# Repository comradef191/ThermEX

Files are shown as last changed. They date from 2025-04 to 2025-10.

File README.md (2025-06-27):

# ThermEX
A BlackPill powered expansion board for Klipper 3D printers, allowing the use of numerous additional Thermistors.

- Can be stacked ontop of or underneith Nyoomies using appropiate spacers
- OpenSource Hardware, licensed under the [OHLv2-S](https://opensource.org/license/cern-ohl-s)
- 10 thermistors wired directly to the STM32
- 16 additional thermistors wired up via 4 ADS1115 ICs
- Powered directly from the USB port
- Uses an ultra-low-noise [TPS7A2033](https://www.ti.com/product/TPS7A20/part-details/TPS7A2033PDBVR) 300mA 3.3v voltage regulator to power all expansion headers and the ADS1115s
- Features native support for the STM32F4x1 BlackPill, with the unused extra GPIO being broken out to a labelled expansion header alongside 3v3 & GND
- Breaks out the I2C2 & I2C3 busses to a pair of dedicated 4-pin JST-XH connectors
- Breaks out the SPI2 bus to a dedicated header, alongside PB12 to act as chip-select

# NOTICE
if you are ordering a batch of PCBs, please for the love of god please use the pre-made gerber files in the [Releases tab](https://github.com/comradef191/ThermEX/releases) instead of downloading the repo, ignoring KiCADs warning you haven't got [a font installed](https://github.com/ETBCOR/nasin-nanpa), and then exporting your own files which both have the I2C bus shorted out (rendering only 10 thermistor ports usable) due to the missing font breaking artwork on the copper layer plus has had markings crediting me destroyed.


## Vendors
UK / EU
- None... yet!

Contact me on Discord if you want to add yourself to this list!

## Bill of Materials
This BoM lists exclusively through-hole components, as SMD components will be assembled for you by JLCPCB
|  Component |QTY | Cost  |  Comment |  Sourcing URL |
|---|----|---|---|---|
|JST-XH 2-Pin | 26 | $0.39 | Thermistor Ports | https://www.lcsc.com/product-detail/Wire-To-Board-Connector_DEALON-XH-D-2A_C5160911.html |
|JST-XH 4-Pin | 2  | $0.52 | I2C Ports | https://www.lcsc.com/product-detail/Wire-To-Board-Connector_JST-B4B-XH-A-LF-SN_C144395.html |
|2.54 Socket, 1x20 | 2  | $0.81 | STM32 Socket | https://www.lcsc.com/product-detail/Female-Headers_Shenzhen-Kinghelm-Elec-KH-2-54FH-1X20P-H8-5_C2905423.html |
|2.54 Header, 2x5 | 3  | $0.40 | GPIO; Cut-Down for SPI | https://www.lcsc.com/product-detail/Pin-Headers_HanElectricity-2541WV-2x05P_C5383106.html |
|STM32F401 Blackpill | 1  | $3.25 | Main controller | https://www.aliexpress.com/item/1005006127461676.html |

# Gallery
*As of 09APR25 no ThermEX26 boards have been produced, thus only KiCad Renders are present currently* 



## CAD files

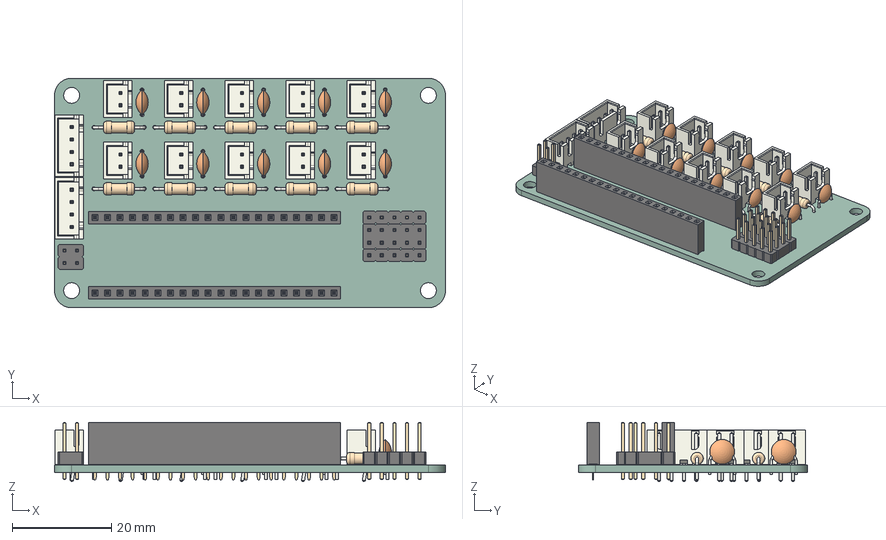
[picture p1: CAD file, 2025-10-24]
Resources/ThermEX10-Simple.step
78.8 x 46.3 x 11.9 mm
R_Axial_DIN0207_L6.3mm_D2.5mm_P10.16mm_Horizontal x 10
C_Disc_D5.0mm_W2.5mm_P5.00mm x 10
PinSocket_1x20_P2.54mm_Vertical x 2
JST_XH_B2B-XH-A_1x02_P2.50mm_Vertical x 10
PinHeader_1x05_P2.54mm_Vertical x 2
PinHeader_2x05_P2.54mm_Vertical
PinHeader_2x02_P2.54mm_Vertical
JST_XH_B4B-XH-A_1x04_P2.50mm_Vertical x 2
ThermEX-Simple_PCB

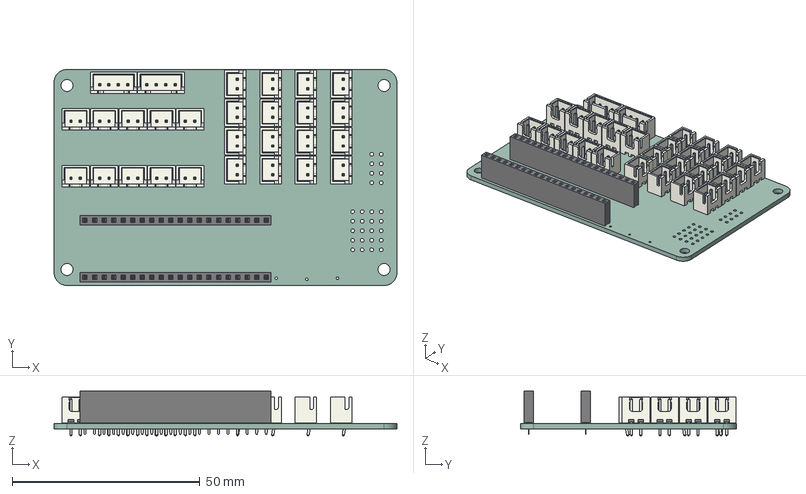
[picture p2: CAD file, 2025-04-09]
Resources/ThermEX26.step
91.3 x 57.5 x 11.9 mm
JST_XH_B2B-XH-A_1x02_P2.50mm_Vertical x 26
JST_XH_B4B-XH-A_1x04_P2.50mm_Vertical x 2
PinSocket_1x20_P2.54mm_Vertical x 2
ThermEX26_PCB

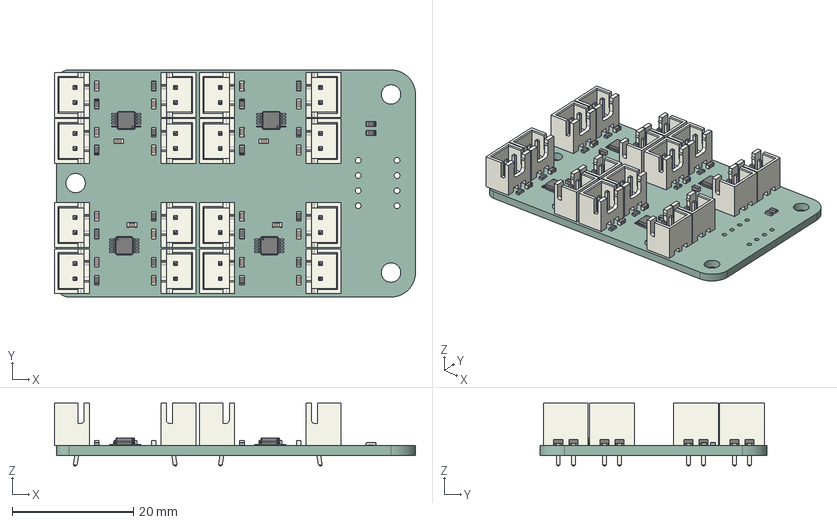
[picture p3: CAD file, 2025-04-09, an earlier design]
LegacyVersions/ThermEX16-V1/ThermEX16.step
59.6 x 37.5 x 10.4 mm
R_0603_1608Metric x 18
JST_B2B_XH_A x 16
C_0603_1608Metric x 20
VSSOP_10_3x3mm_P05mm x 4
ADCExpander_PCB

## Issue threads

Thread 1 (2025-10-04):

Eliminate I2C Bus components

Traveler61, 2025-10-04:
Can you please create a version with the I2C components. I realize it will mean less ports but 10 is enough. Having print failures during large prints, because Klipper can not handle bus fault, is not a good thing. Switching to Kalico is not an option for me.

comradef191, 2025-10-05:
already exists although hasn't been tested
https://github.com/comradef191/ThermEX/tree/main/LegacyVersions/ThermEX10

here's the exported files for that version:

[ThermEX10.zip](https://github.com/user-attachments/files/22705046/ThermEX10.zip)
[positions.csv](https://github.com/user-attachments/files/22705044/positions.csv)
[bom.csv](https://github.com/user-attachments/files/22705045/bom.csv)

Traveler61, 2025-10-06:
Thank you, I had not looked there.

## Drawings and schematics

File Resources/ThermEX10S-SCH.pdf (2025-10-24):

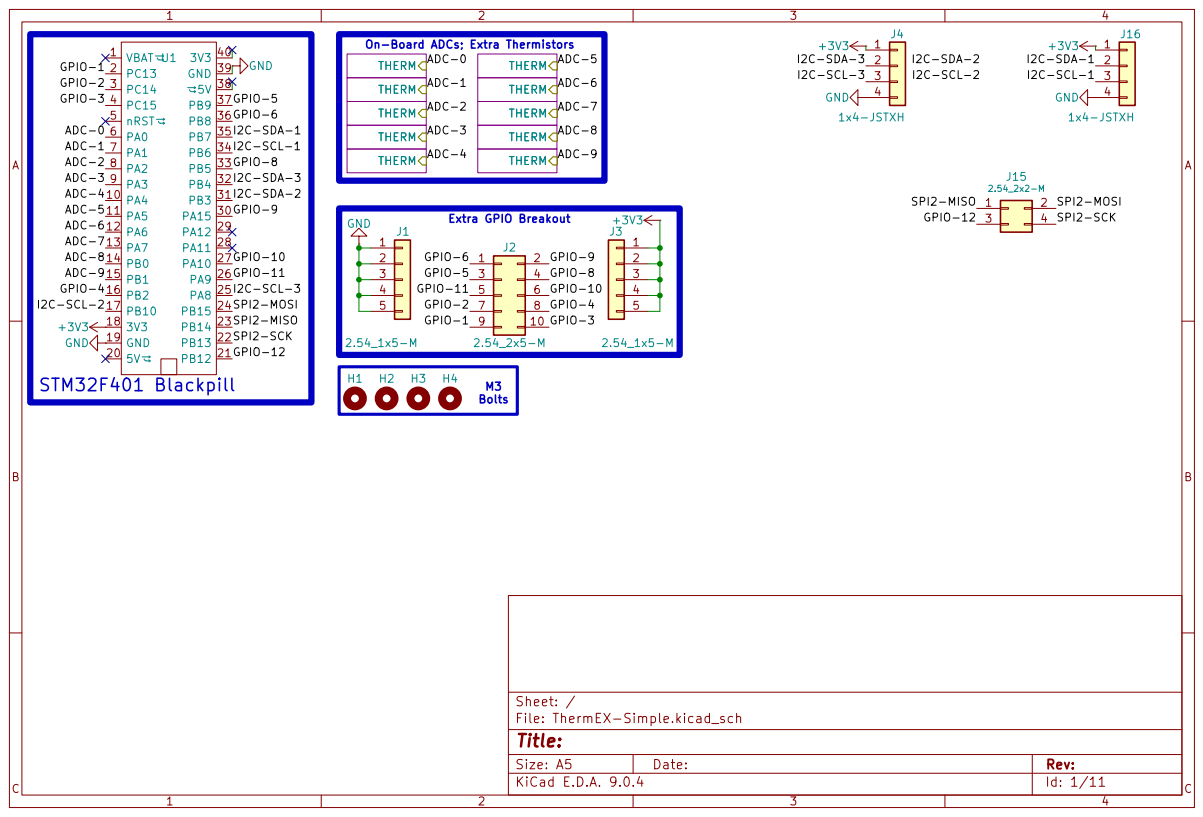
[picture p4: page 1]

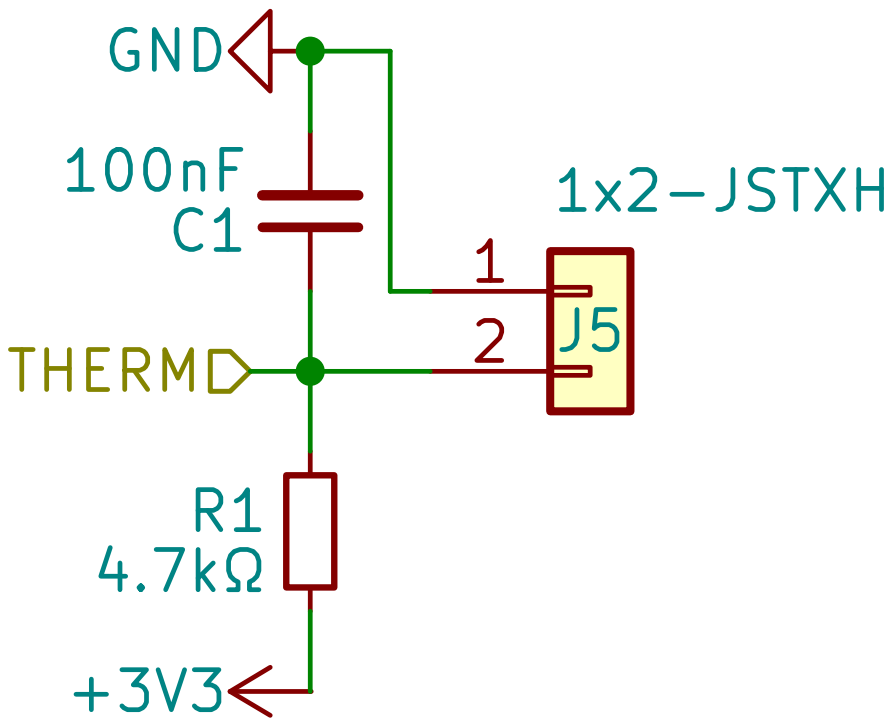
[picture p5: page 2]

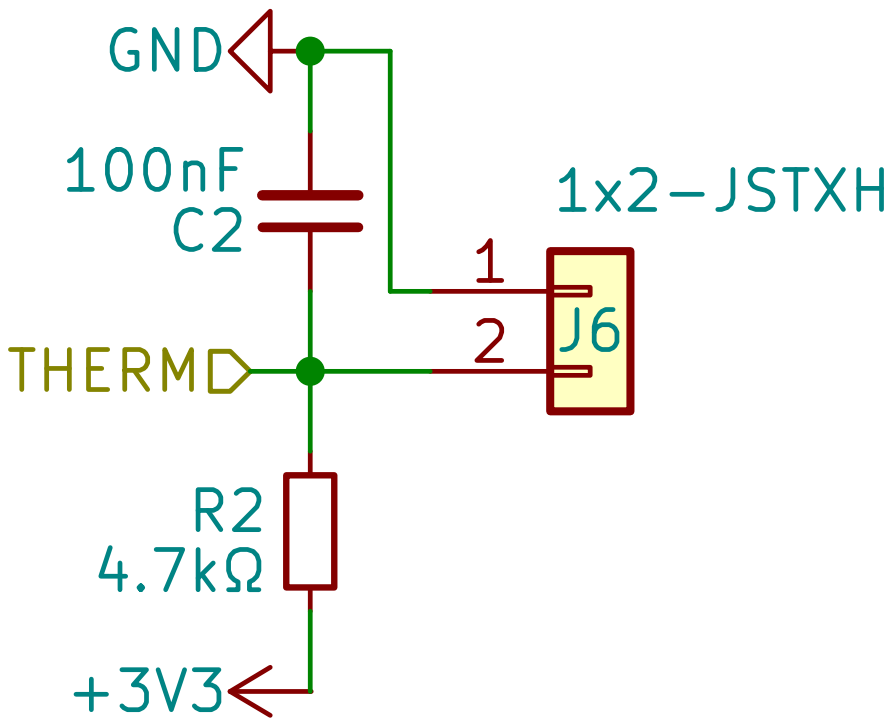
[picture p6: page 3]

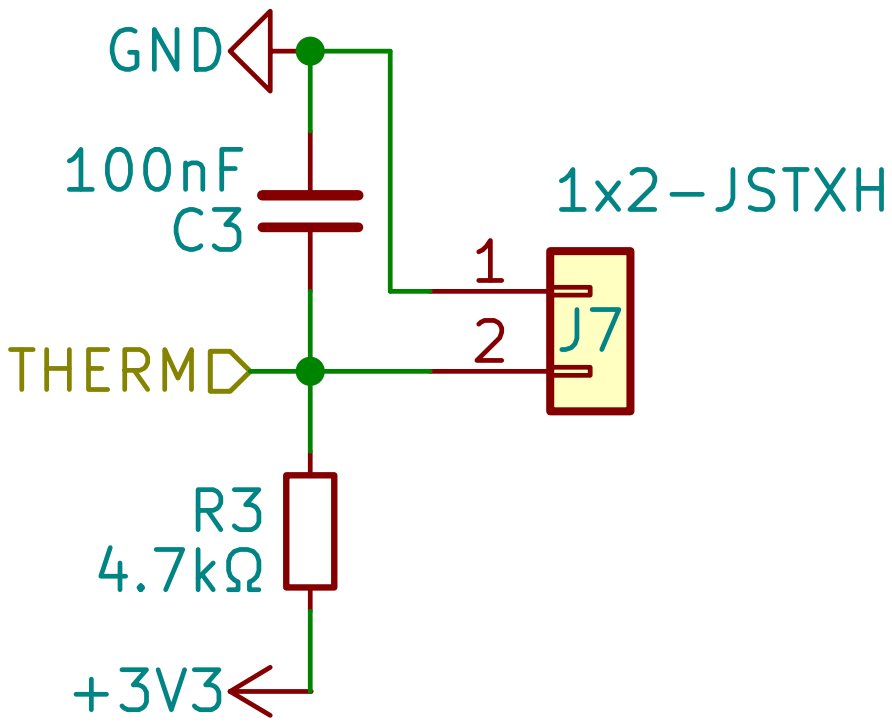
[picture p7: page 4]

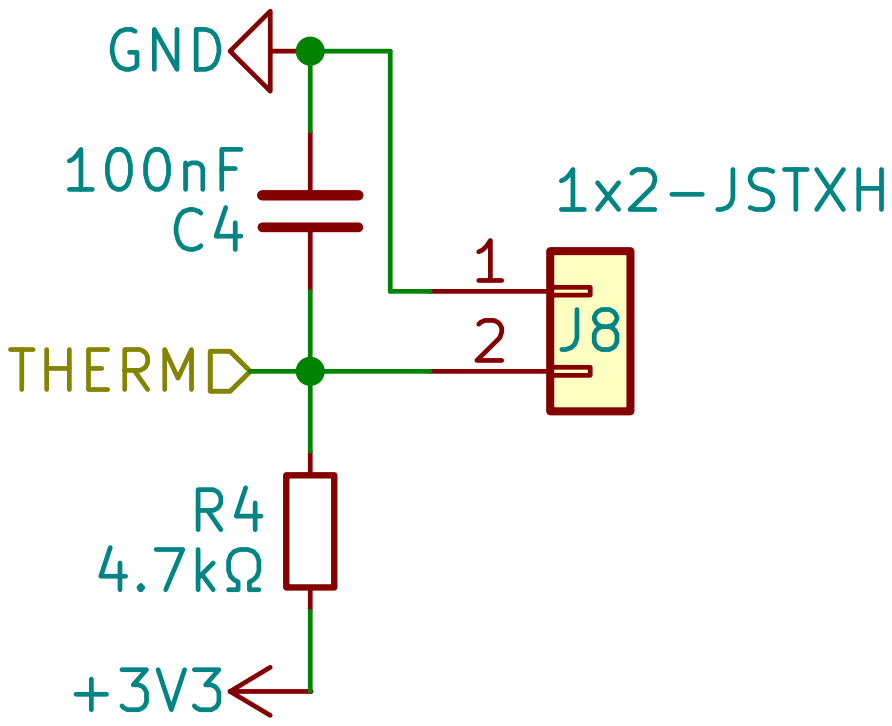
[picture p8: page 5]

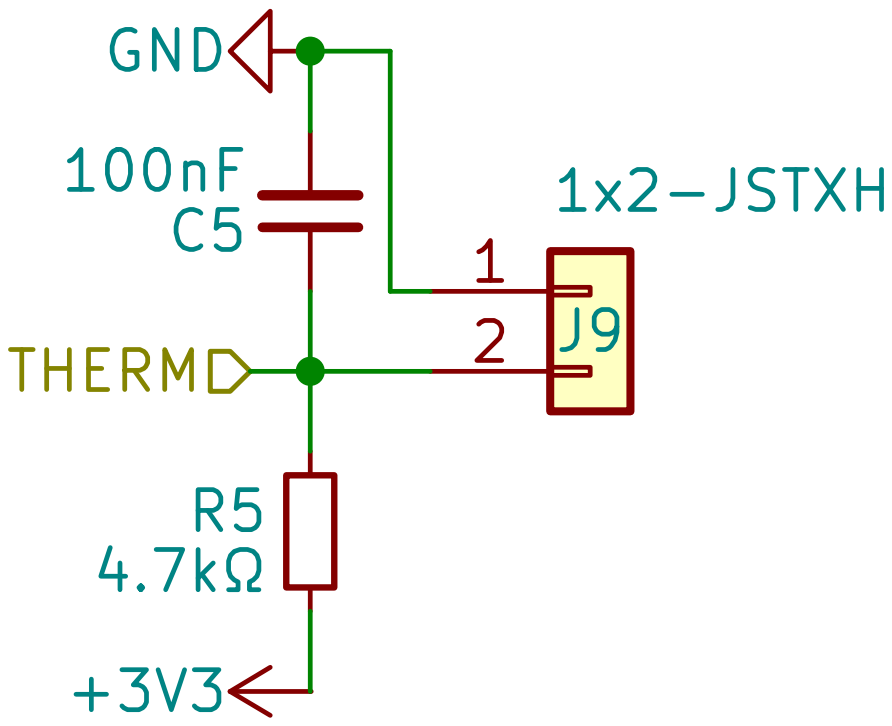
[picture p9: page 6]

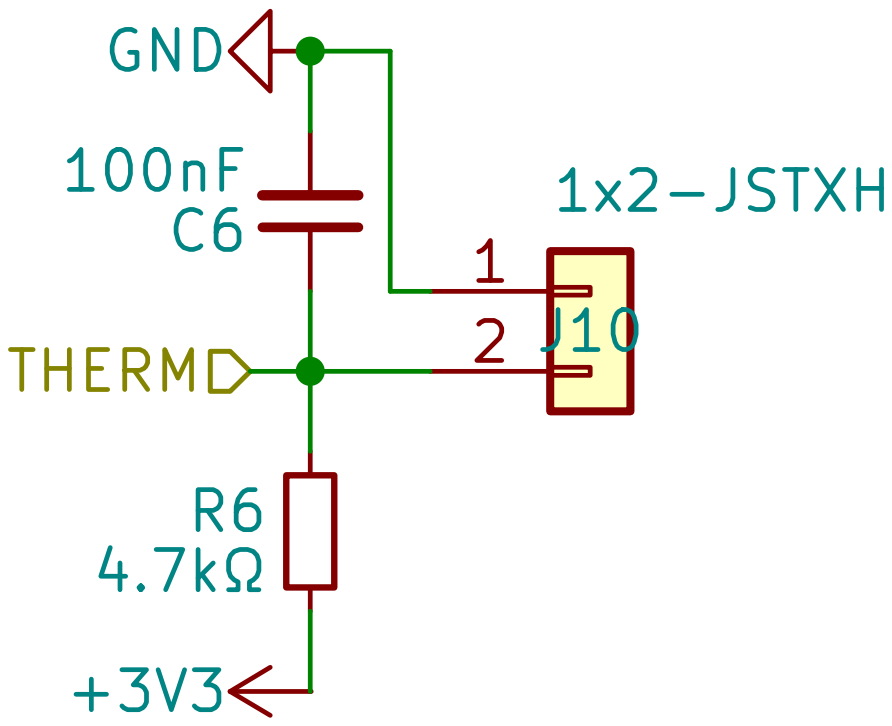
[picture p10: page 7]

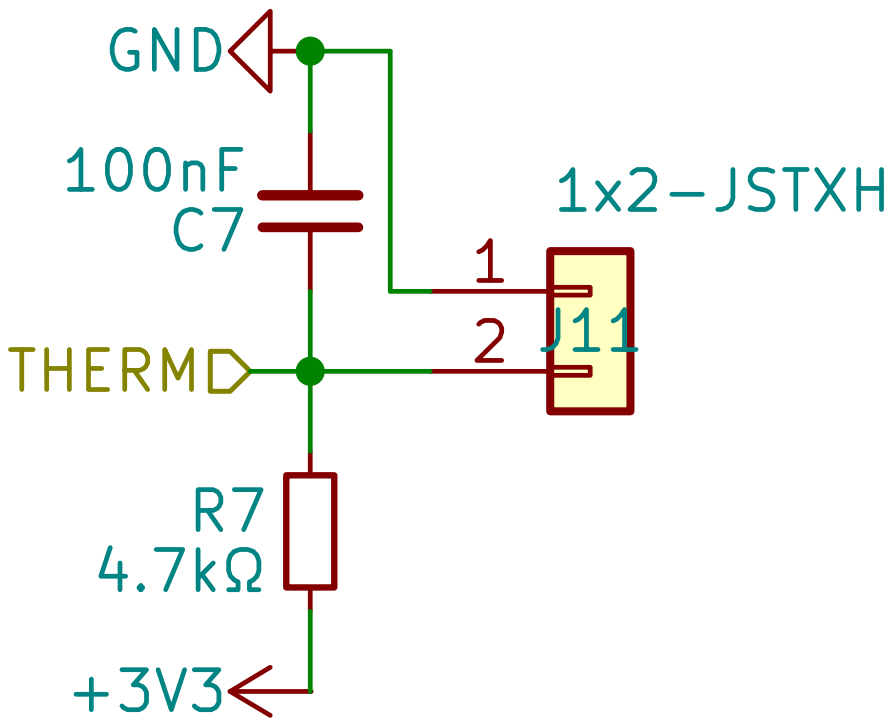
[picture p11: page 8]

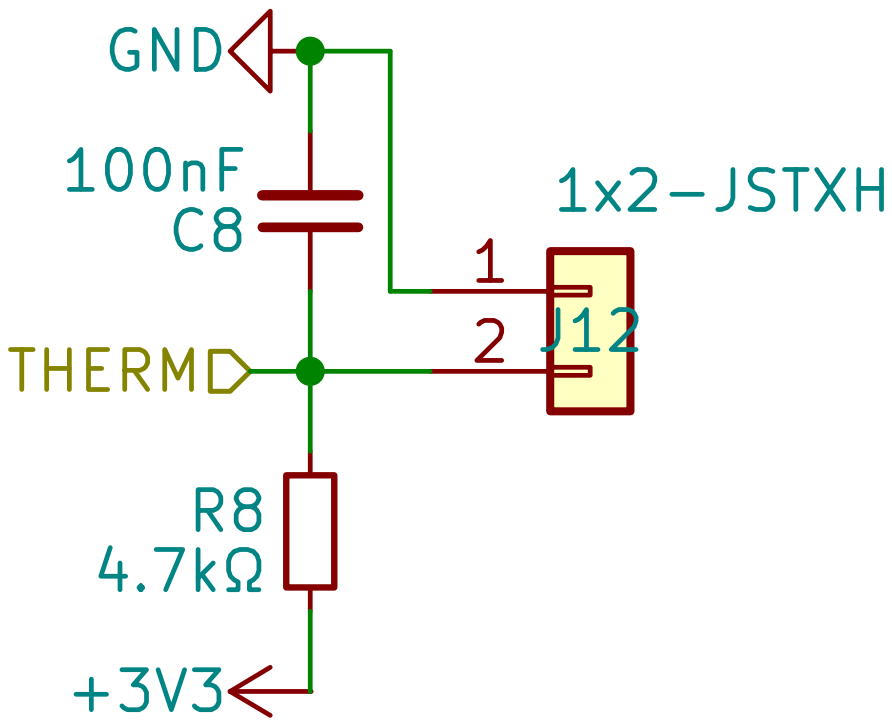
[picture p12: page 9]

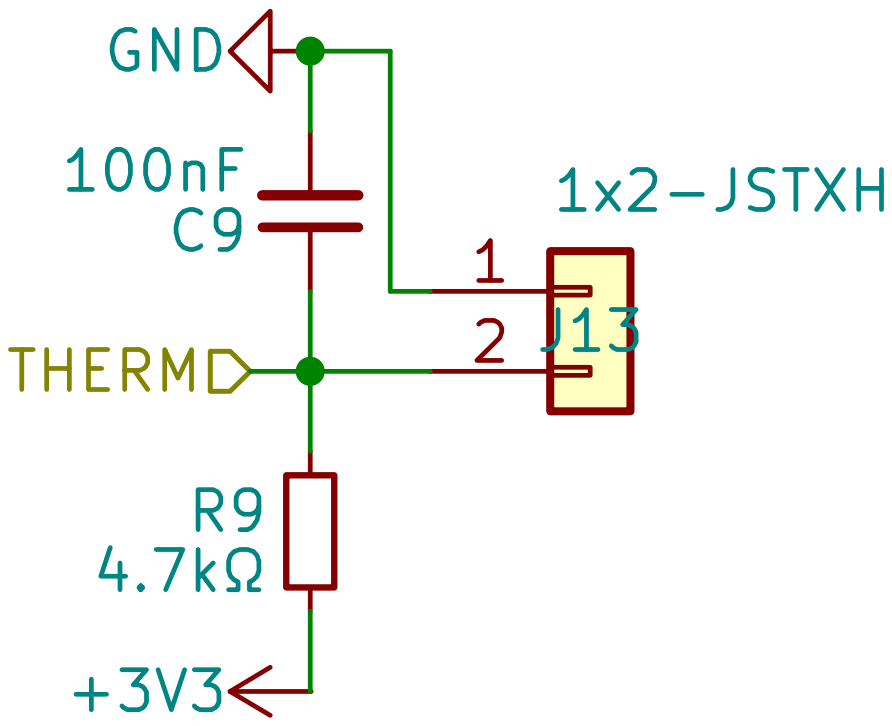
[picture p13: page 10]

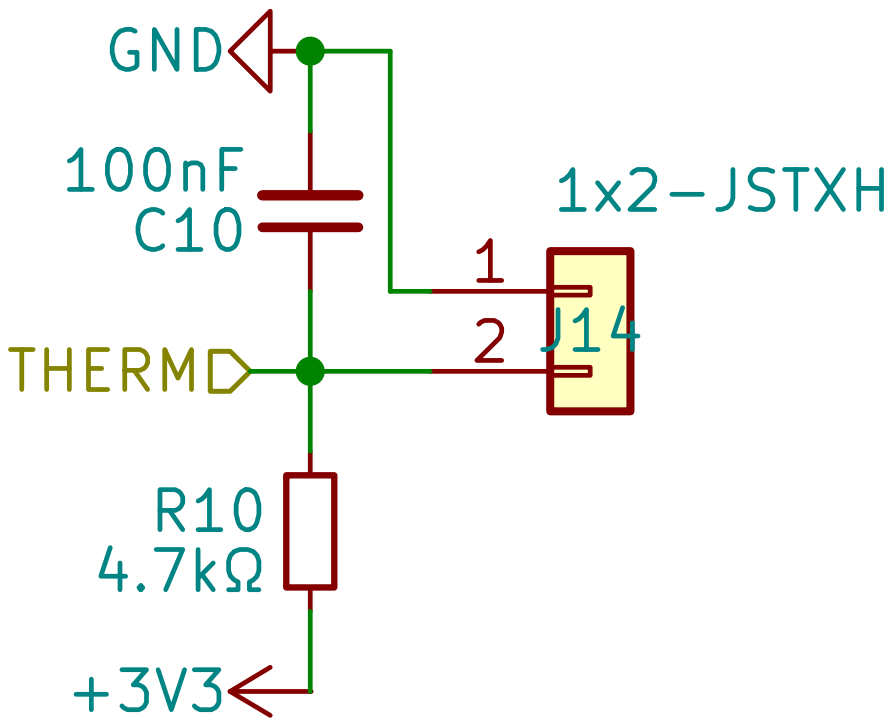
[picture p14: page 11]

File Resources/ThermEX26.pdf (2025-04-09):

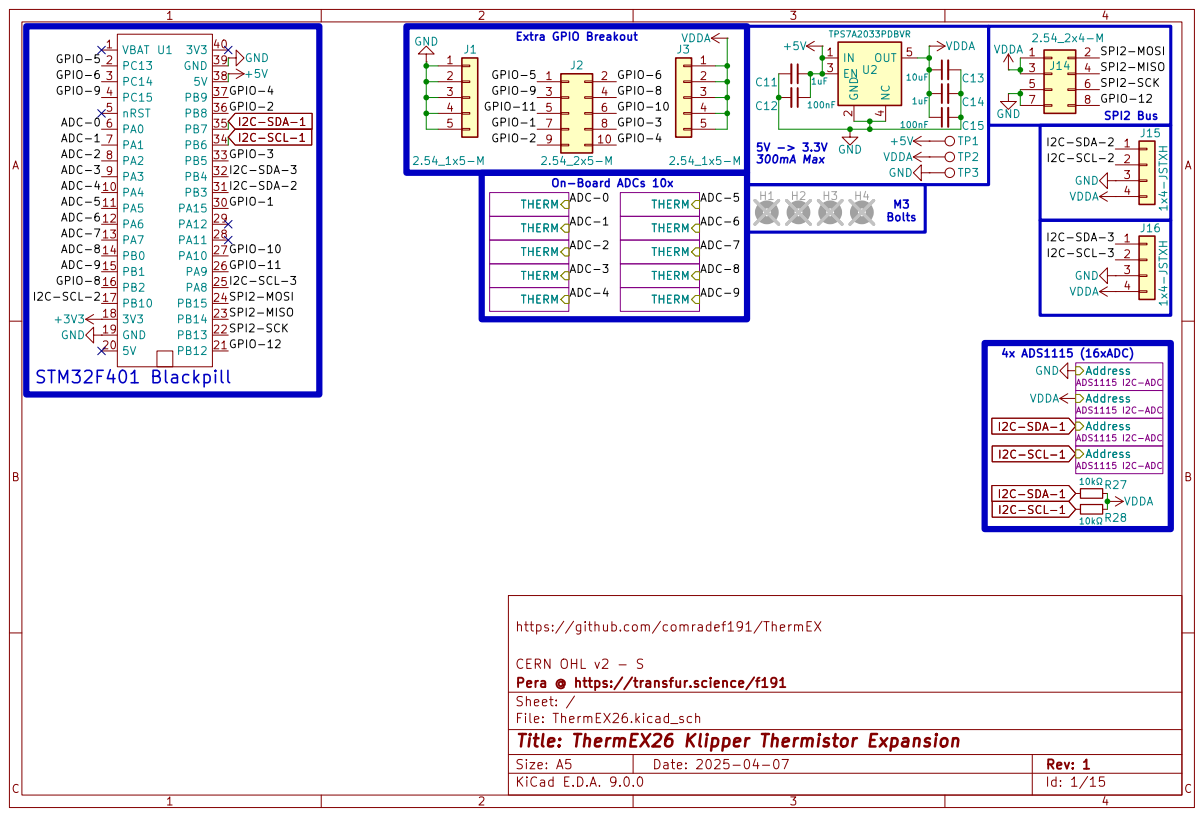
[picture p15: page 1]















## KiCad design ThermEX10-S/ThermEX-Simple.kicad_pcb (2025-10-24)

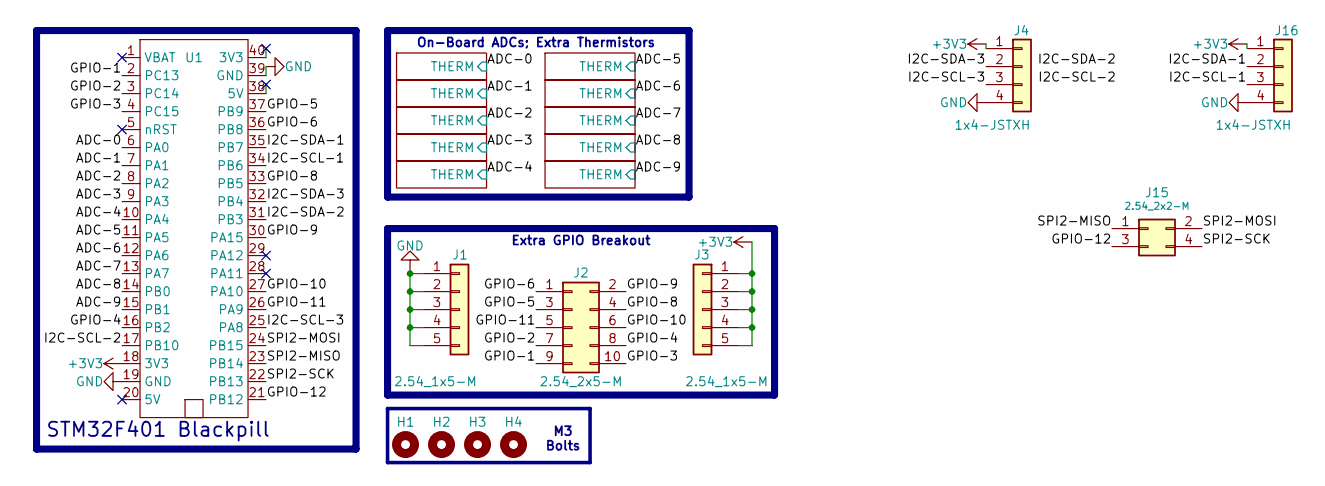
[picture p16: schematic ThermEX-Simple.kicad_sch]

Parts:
H1, H2, H3, H4: MountingHole; M3 Mounting Hole ~ Classic - No Keepout
J1, J3: 2.54_1x5-M; PinHeader_1x05_P2.54mm_Vertical
J2: 2.54_2x5-M; PinHeader_2x05_P2.54mm_Vertical
J4, J16: 1x4-JSTXH; JST_XH_B4B-XH-A_1x04_P2.50mm_Vertical
J15: 2.54_2x2-M; PinHeader_2x02_P2.54mm_Vertical
U1: STM32F401 Blackpill; Socketed MCU - STM32 BlackPill

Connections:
+3V3: J3.1, J3.2, J3.3, J3.4, J3.5, J4.1, J16.1, U1.18 (3V3); also elsewhere on the board
/ADC-0: U1.6 (PA0); also elsewhere on the board
/ADC-1: U1.7 (PA1); also elsewhere on the board
/ADC-2: U1.8 (PA2); also elsewhere on the board
/ADC-3: U1.9 (PA3); also elsewhere on the board
/ADC-4: U1.10 (PA4); also elsewhere on the board
/ADC-5: U1.11 (PA5); also elsewhere on the board
/ADC-6: U1.12 (PA6); also elsewhere on the board
/ADC-7: U1.13 (PA7); also elsewhere on the board
/ADC-8: U1.14 (PB0); also elsewhere on the board
/ADC-9: U1.15 (PB1); also elsewhere on the board
/GPIO-1: J2.9, U1.2 (PC13)
/GPIO-2: J2.7, U1.3 (PC14)
/GPIO-3: J2.10, U1.4 (PC15)
/GPIO-4: J2.8, U1.16 (PB2)
/GPIO-5: J2.3, U1.37 (PB9)
/GPIO-6: J2.1, U1.36 (PB8)
/GPIO-8: J2.4, U1.33 (PB5)
/GPIO-9: J2.2, U1.30 (PA15)
/GPIO-10: J2.6, U1.27 (PA10)
/GPIO-11: J2.5, U1.26 (PA9)
/GPIO-12: J15.3, U1.21 (PB12)
/I2C-SCL-1: J16.3, U1.34 (PB6)
/I2C-SCL-2: U1.17 (PB10)
/I2C-SCL-3: J4.3, U1.25 (PA8)
/I2C-SDA-1: J16.2, U1.35 (PB7)
/I2C-SDA-2: U1.31 (PB3)
/I2C-SDA-3: J4.2, U1.32 (PB4)
/SPI2-MISO: J15.1, U1.23 (PB14)
/SPI2-MOSI: J15.2, U1.24 (PB15)
/SPI2-SCK: J15.4, U1.22 (PB13)
GND: J1.1, J1.2, J1.3, J1.4, J1.5, J4.4, J16.4, U1.19 (GND), U1.39 (GND); also elsewhere on the board

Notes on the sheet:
STM32F401 Blackpill
M3 Bolts
Extra GPIO Breakout
On-Board ADCs; Extra Thermistors

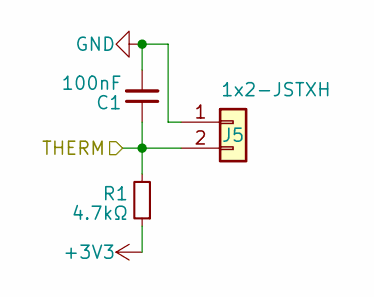
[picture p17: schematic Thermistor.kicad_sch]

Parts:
C1: 100nF; C_Disc_D5.0mm_W2.5mm_P5.00mm
J5: 1x2-JSTXH; JST-XH_1x02-V ~ Custom
R1: 4.7kΩ; R_Axial_DIN0207_L6.3mm_D2.5mm_P10.16mm_Horizontal

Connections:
+3V3: R1.1; also elsewhere on the board
/ADC-0: C1.1, J5.2, R1.2; also elsewhere on the board
GND: C1.2, J5.1; also elsewhere on the board

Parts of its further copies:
C2, C3, C4, C5, C6, C7, C8, C9, C10: 100nF; C_Disc_D5.0mm_W2.5mm_P5.00mm
J6, J7, J8, J9, J10, J11, J12, J13, J14: 1x2-JSTXH; JST-XH_1x02-V ~ Custom
R2, R3, R4, R5, R6, R7, R8, R9, R10: 4.7kΩ; R_Axial_DIN0207_L6.3mm_D2.5mm_P10.16mm_Horizontal

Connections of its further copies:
+3V3: R2.1, R3.1, R4.1, R5.1, R6.1, R7.1, R8.1, R9.1, R10.1; also elsewhere on the board
/ADC-1: C2.1, J6.2, R2.2; also elsewhere on the board
/ADC-2: C3.1, J7.2, R3.2; also elsewhere on the board
/ADC-3: C4.1, J8.2, R4.2; also elsewhere on the board
/ADC-4: C5.1, J9.2, R5.2; also elsewhere on the board
/ADC-5: C6.1, J10.2, R6.2; also elsewhere on the board
/ADC-6: C7.1, J11.2, R7.2; also elsewhere on the board
/ADC-7: C8.1, J12.2, R8.2; also elsewhere on the board
/ADC-8: C9.1, J13.2, R9.2; also elsewhere on the board
/ADC-9: C10.1, J14.2, R10.2; also elsewhere on the board
GND: C2.2, C3.2, C4.2, C5.2, C6.2, C7.2, C8.2, C9.2, C10.2, J6.1, J7.1, J8.1, J9.1, J10.1, J11.1, J12.1, J13.1, J14.1; also elsewhere on the board

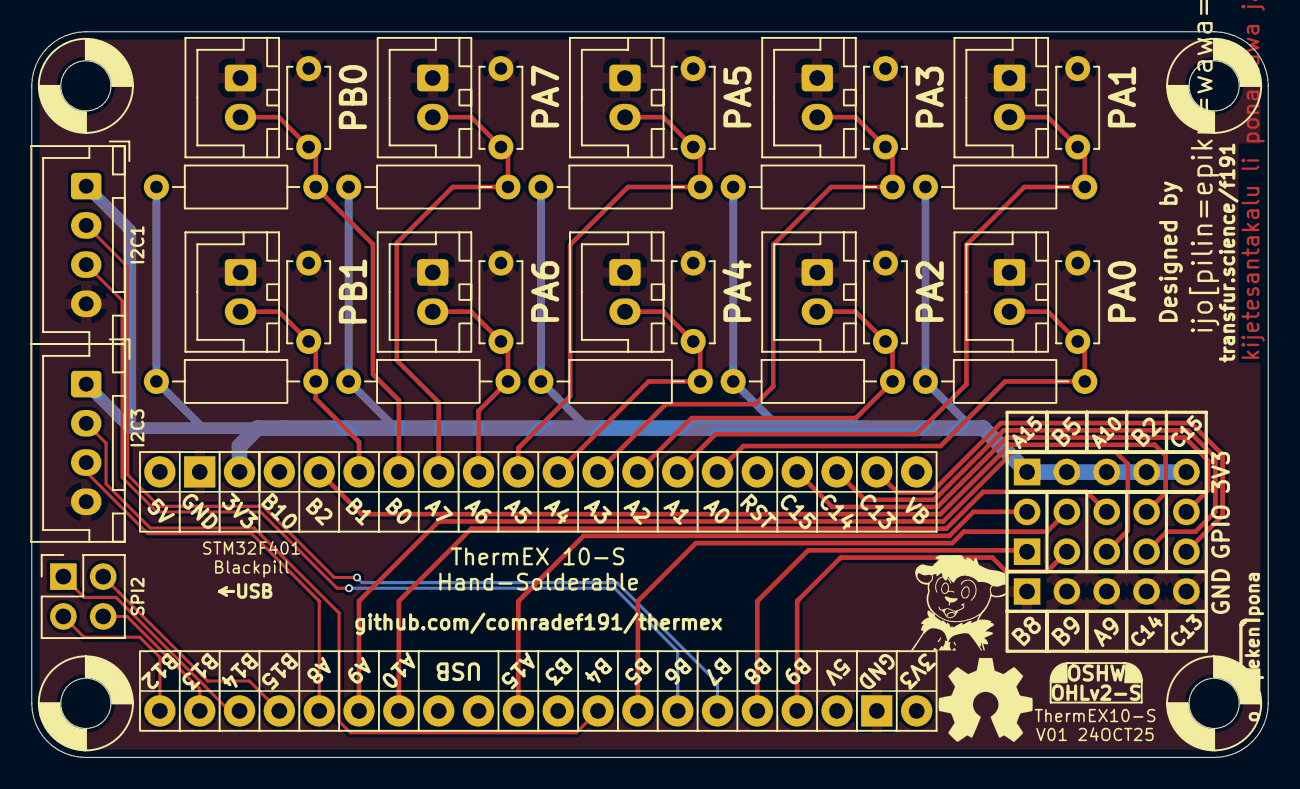
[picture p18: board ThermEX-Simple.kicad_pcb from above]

Board: 2 copper layers, 78.9 x 46.3 mm, 41 parts (0 on the bottom side), 30 nets.

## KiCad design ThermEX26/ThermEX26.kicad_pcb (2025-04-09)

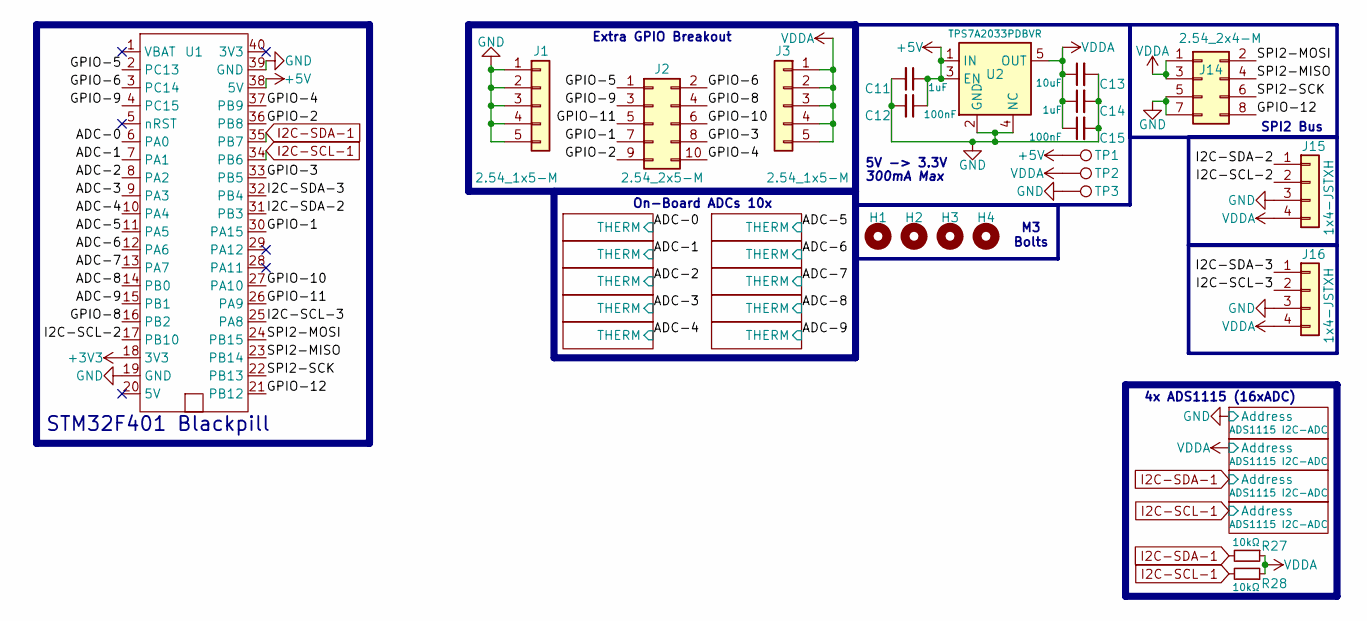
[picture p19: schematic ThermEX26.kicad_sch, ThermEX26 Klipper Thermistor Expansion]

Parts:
C11, C14: 1uF; C_0603_1608Metric; LCSC C15849
C12, C15: 100nF; C_0603_1608Metric; LCSC C14663
C13: 10uF; C_0603_1608Metric; LCSC C96446
H1, H2, H3, H4: M3 Mounting Hole; M3 Mounting Hole ~ Classic
J1, J3: 2.54_1x5-M; PinHeader_1x05_P2.54mm_Vertical
J2: 2.54_2x5-M; PinHeader_2x05_P2.54mm_Vertical
J14: 2.54_2x4-M; PinHeader_2x04_P2.54mm_Vertical
J15, J16: 1x4-JSTXH; JST_XH_B4B-XH-A_1x04_P2.50mm_Vertical; LCSC C144395
R27, R28: 10kΩ; R_0603_1608Metric_Pad0.98x0.95mm_HandSolder; LCSC C25804
TP1, TP2, TP3: TestPoint; TestPoint_THTPad_D1.5mm_Drill0.7mm
U1: Socketed MCU - STM32 BlackPill
U2: TPS7A2033PDBVR; SOT-23-5; LCSC C2862740

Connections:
+3V3: U1.18 (3V3); also elsewhere on the board
+5V: C11.1, C12.1, TP1.1, U1.38 (5V), U2.1 (IN), U2.3 (EN)
/ADC-0: U1.6 (PA0); also elsewhere on the board
/ADC-1: U1.7 (PA1); also elsewhere on the board
/ADC-2: U1.8 (PA2); also elsewhere on the board
/ADC-3: U1.9 (PA3); also elsewhere on the board
/ADC-4: U1.10 (PA4); also elsewhere on the board
/ADC-5: U1.11 (PA5); also elsewhere on the board
/ADC-6: U1.12 (PA6); also elsewhere on the board
/ADC-7: U1.13 (PA7); also elsewhere on the board
/ADC-8: U1.14 (PB0); also elsewhere on the board
/ADC-9: U1.15 (PB1); also elsewhere on the board
/GPIO-1: J2.7, U1.30 (PA15)
/GPIO-2: J2.9, U1.36 (PB8)
/GPIO-3: J2.8, U1.33 (PB5)
/GPIO-4: J2.10, U1.37 (PB9)
/GPIO-5: J2.1, U1.2 (PC13)
/GPIO-6: J2.2, U1.3 (PC14)
/GPIO-8: J2.4, U1.16 (PB2)
/GPIO-9: J2.3, U1.4 (PC15)
/GPIO-10: J2.6, U1.27 (PA10)
/GPIO-11: J2.5, U1.26 (PA9)
/GPIO-12: J14.8, U1.21 (PB12)
/I2C-SCL-2: J15.2, U1.17 (PB10)
/I2C-SCL-3: J16.2, U1.25 (PA8)
/I2C-SDA-2: J15.1, U1.31 (PB3)
/I2C-SDA-3: J16.1, U1.32 (PB4)
/SPI2-MISO: J14.4, U1.23 (PB14)
/SPI2-MOSI: J14.2, U1.24 (PB15)
/SPI2-SCK: J14.6, U1.22 (PB13)
GND: C11.2, C12.2, C13.2, C14.2, C15.2, J1.1, J1.2, J1.3, J1.4, J1.5, J14.5, J14.7, J15.3, J16.3, TP3.1, U1.19 (GND), U1.39 (GND), U2.2 (GND), U2.4 (NC); also elsewhere on the board
I2C-SCL-1: R28.2, U1.34 (PB6); also elsewhere on the board
I2C-SDA-1: R27.2, U1.35 (PB7); also elsewhere on the board
VDDA: C13.1, C14.1, C15.1, J3.1, J3.2, J3.3, J3.4, J3.5, J14.1, J14.3, J15.4, J16.4, R27.1, R28.1, TP2.1, U2.5 (OUT); also elsewhere on the board

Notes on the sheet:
M3 Bolts
300mA Max
STM32F401 Blackpill
SPI2 Bus
Extra GPIO Breakout
On-Board ADCs 10x
4x ADS1115 (16xADC)
5V -> 3.3V

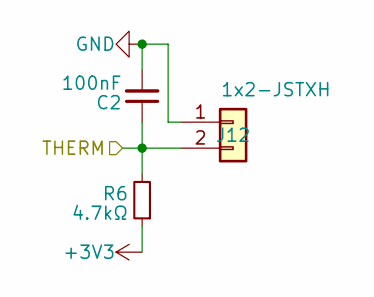
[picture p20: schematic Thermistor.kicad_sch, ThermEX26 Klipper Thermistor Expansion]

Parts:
C2: 100nF; C_0603_1608Metric; LCSC C14663
J12: 1x2-JSTXH; JST-XH_1x02-V ~ Custom; LCSC C5160911
R6: 4.7kΩ; R_0603_1608Metric; LCSC C23162

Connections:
+3V3: R6.1; also elsewhere on the board
/ADC-0: C2.1, J12.2, R6.2; also elsewhere on the board
GND: C2.2, J12.1; also elsewhere on the board

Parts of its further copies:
C1, C3, C4, C5, C6, C7, C8, C9, C10: 100nF; C_0603_1608Metric; LCSC C14663
J4, J5, J6, J7, J8, J9, J10, J11, J13: 1x2-JSTXH; JST-XH_1x02-V ~ Custom; LCSC C5160911
R1, R2, R3, R4, R5, R7, R8, R9, R10: 4.7kΩ; R_0603_1608Metric; LCSC C23162

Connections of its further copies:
+3V3: R1.1, R2.1, R3.1, R4.1, R5.1, R7.1, R8.1, R9.1, R10.1; also elsewhere on the board
/ADC-1: C1.1, J4.2, R1.2; also elsewhere on the board
/ADC-2: C3.1, J5.2, R2.2; also elsewhere on the board
/ADC-3: C4.1, J6.2, R3.2; also elsewhere on the board
/ADC-4: C5.1, J7.2, R4.2; also elsewhere on the board
/ADC-5: C8.1, J8.2, R9.2; also elsewhere on the board
/ADC-6: C6.1, J9.2, R5.2; also elsewhere on the board
/ADC-7: C7.1, J10.2, R7.2; also elsewhere on the board
/ADC-8: C9.1, J11.2, R8.2; also elsewhere on the board
/ADC-9: C10.1, J13.2, R10.2; also elsewhere on the board
GND: C1.2, C3.2, C4.2, C5.2, C6.2, C7.2, C8.2, C9.2, C10.2, J4.1, J5.1, J6.1, J7.1, J8.1, J9.1, J10.1, J11.1, J13.1; also elsewhere on the board

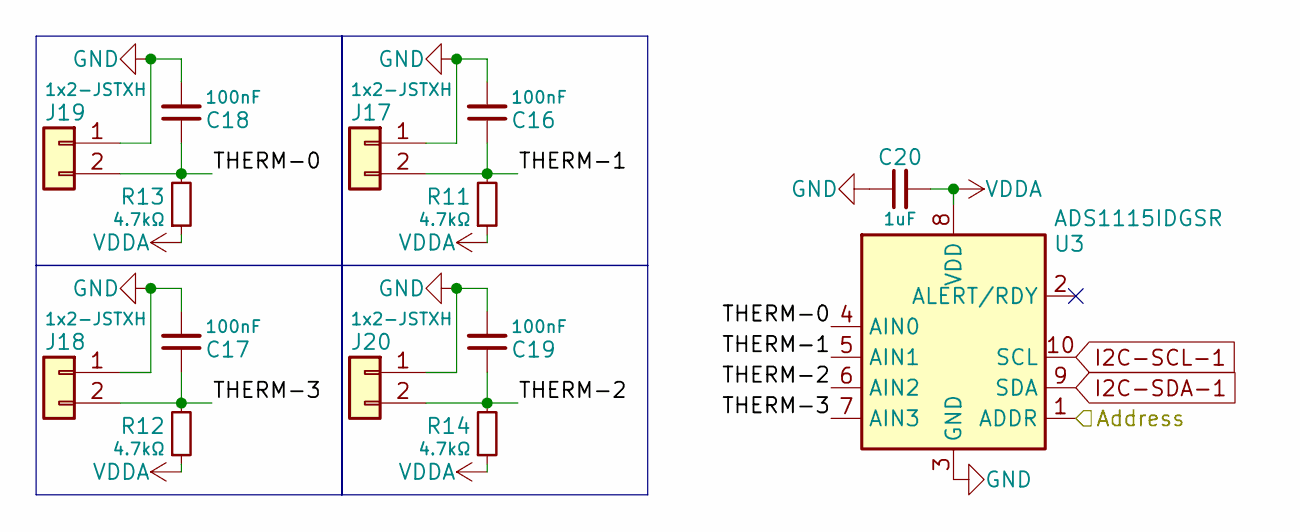
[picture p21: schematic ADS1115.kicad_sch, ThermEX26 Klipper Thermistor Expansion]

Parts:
C16, C17, C18, C19: 100nF; C_0603_1608Metric; LCSC C14663
C20: 1uF; C_0603_1608Metric; LCSC C15849
J17, J18, J19, J20: 1x2-JSTXH; JST-XH_1x02-V ~ Custom; LCSC C5160911
R11, R12, R13, R14: 4.7kΩ; R_0603_1608Metric; LCSC C23162
U3: ADS1115IDGSR; VSSOP-10_3x3mm_P0.5mm; LCSC C37593

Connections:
/ADSChip 1/THERM-0: C18.1, J19.2, R13.2, U3.4 (AIN0)
/ADSChip 1/THERM-1: C16.1, J17.2, R11.2, U3.5 (AIN1)
/ADSChip 1/THERM-2: C19.1, J20.2, R14.2, U3.6 (AIN2)
/ADSChip 1/THERM-3: C17.1, J18.2, R12.2, U3.7 (AIN3)
GND: C16.2, C17.2, C18.2, C19.2, C20.1, J17.1, J18.1, J19.1, J20.1, U3.1 (ADDR), U3.3 (GND); also elsewhere on the board
I2C-SCL-1: U3.10 (SCL); also elsewhere on the board
I2C-SDA-1: U3.9 (SDA); also elsewhere on the board
VDDA: C20.2, R11.1, R12.1, R13.1, R14.1, U3.8 (VDD); also elsewhere on the board

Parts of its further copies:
C21, C22, C23, C24, C26, C27, C28, C29, C31, C32, C33, C34: 100nF; C_0603_1608Metric; LCSC C14663
C25, C30, C35: 1uF; C_0603_1608Metric; LCSC C15849
J21, J22, J23, J24, J25, J26, J27, J28, J29, J30, J31, J32: 1x2-JSTXH; JST-XH_1x02-V ~ Custom; LCSC C5160911
R15, R16, R17, R18, R19, R20, R21, R22, R23, R24, R25, R26: 4.7kΩ; R_0603_1608Metric; LCSC C23162
U4, U5, U6: ADS1115IDGSR; VSSOP-10_3x3mm_P0.5mm; LCSC C37593

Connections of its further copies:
/ADSChip 2/THERM-0: C23.1, J23.2, R17.2, U4.4 (AIN0)
/ADSChip 2/THERM-1: C21.1, J21.2, R15.2, U4.5 (AIN1)
/ADSChip 2/THERM-2: C24.1, J24.2, R18.2, U4.6 (AIN2)
/ADSChip 2/THERM-3: C22.1, J22.2, R16.2, U4.7 (AIN3)
/ADSChip 3/THERM-0: C28.1, J27.2, R21.2, U5.4 (AIN0)
/ADSChip 3/THERM-1: C26.1, J25.2, R19.2, U5.5 (AIN1)
/ADSChip 3/THERM-2: C29.1, J28.2, R22.2, U5.6 (AIN2)
/ADSChip 3/THERM-3: C27.1, J26.2, R20.2, U5.7 (AIN3)
/ADSChip 4/THERM-0: C33.1, J31.2, R25.2, U6.4 (AIN0)
/ADSChip 4/THERM-1: C31.1, J29.2, R23.2, U6.5 (AIN1)
/ADSChip 4/THERM-2: C34.1, J32.2, R26.2, U6.6 (AIN2)
/ADSChip 4/THERM-3: C32.1, J30.2, R24.2, U6.7 (AIN3)
GND: C21.2, C22.2, C23.2, C24.2, C25.1, C26.2, C27.2, C28.2, C29.2, C30.1, C31.2, C32.2, C33.2, C34.2, C35.1, J21.1, J22.1, J23.1, J24.1, J25.1, J26.1, J27.1, J28.1, J29.1, J30.1, J31.1, J32.1, U4.3 (GND), U5.3 (GND), U6.3 (GND); also elsewhere on the board
I2C-SCL-1: U4.10 (SCL), U5.10 (SCL), U6.1 (ADDR), U6.10 (SCL); also elsewhere on the board
I2C-SDA-1: U4.9 (SDA), U5.1 (ADDR), U5.9 (SDA), U6.9 (SDA); also elsewhere on the board
VDDA: C25.2, C30.2, C35.2, R15.1, R16.1, R17.1, R18.1, R19.1, R20.1, R21.1, R22.1, R23.1, R24.1, R25.1, R26.1, U4.1 (ADDR), U4.8 (VDD), U5.8 (VDD), U6.8 (VDD); also elsewhere on the board

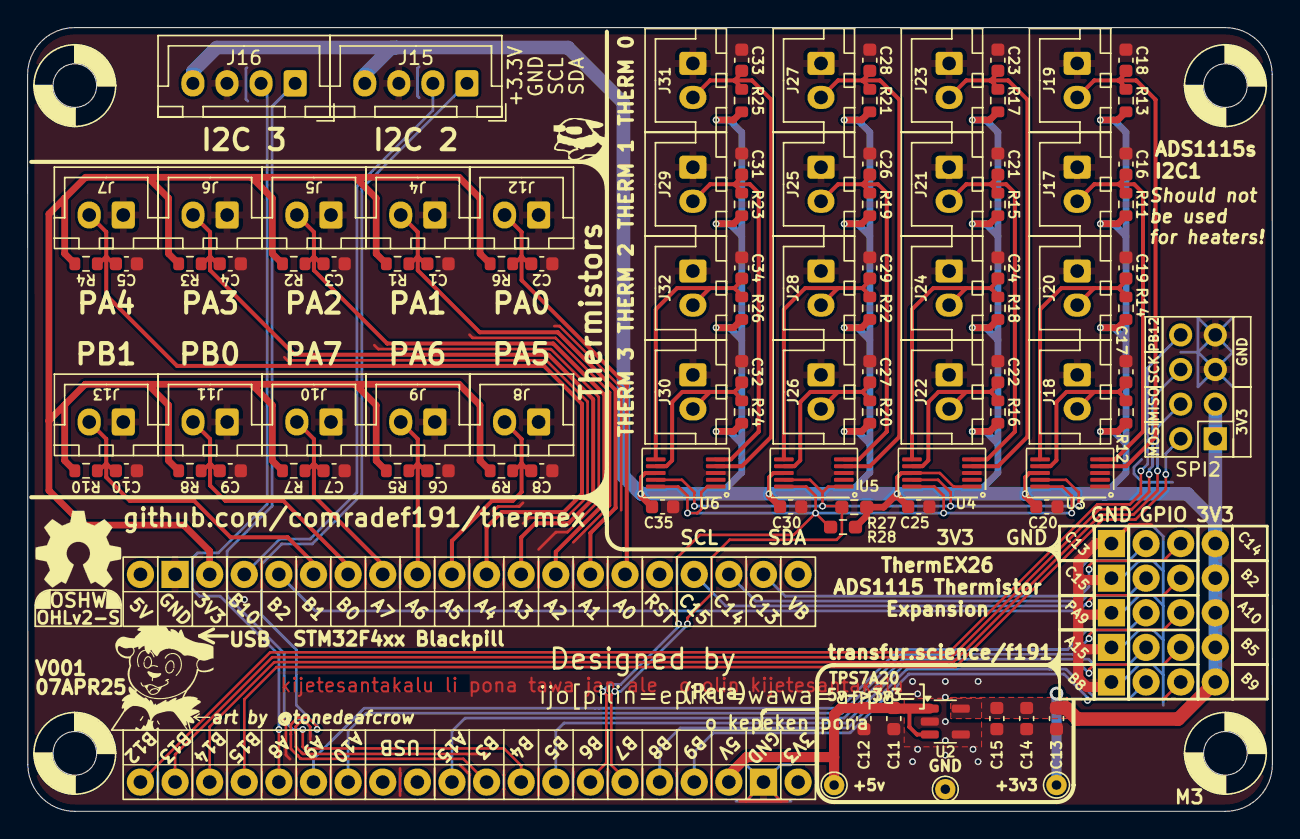
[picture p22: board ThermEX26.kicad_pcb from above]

Board: 2 copper layers, 91.3 x 57.5 mm, 108 parts (0 on the bottom side), 50 nets.

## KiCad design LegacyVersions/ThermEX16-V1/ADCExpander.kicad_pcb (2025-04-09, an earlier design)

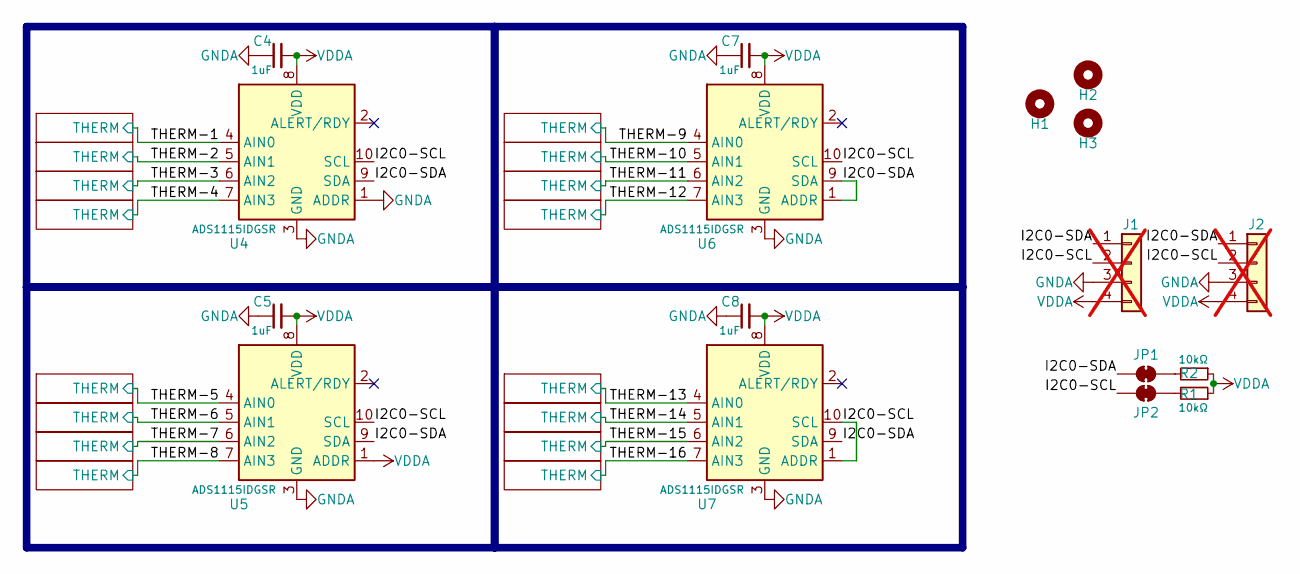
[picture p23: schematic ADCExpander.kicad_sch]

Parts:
C4, C5, C7, C8: 1uF; C_0603_1608Metric; LCSC C15849
H1, H2, H3: MountingHole; M3 Mounting Hole ~ Classic; LCSC N/A
J1, J2: Conn_01x04; JST_XH_B4B-XH-A_1x04_P2.50mm_Vertical; LCSC C144395; not fitted
JP1, JP2: SolderJumper_2_Bridged; SolderJumper-2_P1.3mm_Bridged_RoundedPad1.0x1.5mm; LCSC N/A
R1, R2: 10kΩ; R_0603_1608Metric_Pad0.98x0.95mm_HandSolder; LCSC C25804
U4, U5, U6, U7: ADS1115IDGSR; VSSOP-10_3x3mm_P0.5mm; LCSC C37593

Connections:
/I2C0-SCL: J1.2, J2.2, JP2.2 (B), U4.10 (SCL), U5.10 (SCL), U6.10 (SCL), U7.1 (ADDR), U7.10 (SCL)
/I2C0-SDA: J1.1, J2.1, JP1.2 (B), U4.9 (SDA), U5.9 (SDA), U6.1 (ADDR), U6.9 (SDA), U7.9 (SDA)
/THERM-1: U4.4 (AIN0); also elsewhere on the board
/THERM-2: U4.5 (AIN1); also elsewhere on the board
/THERM-3: U4.6 (AIN2); also elsewhere on the board
/THERM-4: U4.7 (AIN3); also elsewhere on the board
/THERM-5: U5.4 (AIN0); also elsewhere on the board
/THERM-6: U5.5 (AIN1); also elsewhere on the board
/THERM-7: U5.6 (AIN2); also elsewhere on the board
/THERM-8: U5.7 (AIN3); also elsewhere on the board
/THERM-9: U6.4 (AIN0); also elsewhere on the board
/THERM-10: U6.5 (AIN1); also elsewhere on the board
/THERM-11: U6.6 (AIN2); also elsewhere on the board
/THERM-12: U6.7 (AIN3); also elsewhere on the board
/THERM-13: U7.4 (AIN0); also elsewhere on the board
/THERM-14: U7.5 (AIN1); also elsewhere on the board
/THERM-15: U7.6 (AIN2); also elsewhere on the board
/THERM-16: U7.7 (AIN3); also elsewhere on the board
GNDA: C4.1, C5.1, C7.1, C8.1, J1.3, J2.3, U4.1 (ADDR), U4.3 (GND), U5.3 (GND), U6.3 (GND), U7.3 (GND); also elsewhere on the board
unnamed: JP1.1 (A), R2.2
unnamed: JP2.1 (A), R1.2
VDDA: C4.2, C5.2, C7.2, C8.2, J1.4, J2.4, R1.1, R2.1, U4.8 (VDD), U5.1 (ADDR), U5.8 (VDD), U6.8 (VDD), U7.8 (VDD); also elsewhere on the board

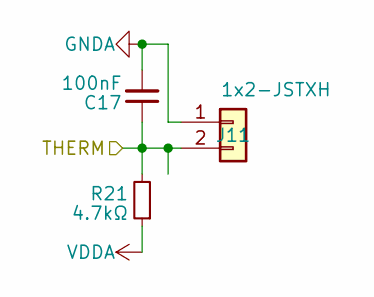
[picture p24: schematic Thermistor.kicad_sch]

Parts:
C17: 100nF; C_0603_1608Metric; LCSC C14663
J11: 1x2-JSTXH; JST-XH_1x02-V ~ Custom; LCSC C5160911
R21: 4.7kΩ; R_0603_1608Metric; LCSC C2989672

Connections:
/THERM-9: C17.1, J11.2, R21.2; also elsewhere on the board
GNDA: C17.2, J11.1; also elsewhere on the board
VDDA: R21.1; also elsewhere on the board

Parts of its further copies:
C9, C10, C11, C12, C13, C14, C15, C16, C18, C19, C20, C21, C22, C23, C24: 100nF; C_0603_1608Metric; LCSC C14663
J3, J4, J5, J6, J7, J8, J9, J10, J12, J13, J14, J15, J16, J17, J18: 1x2-JSTXH; JST-XH_1x02-V ~ Custom; LCSC C5160911
R13, R14, R15, R16, R17, R18, R19, R20, R22, R23, R24, R25, R26, R27, R28: 4.7kΩ; R_0603_1608Metric; LCSC C2989672

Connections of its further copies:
/THERM-1: C9.1, J3.2, R13.2; also elsewhere on the board
/THERM-2: C10.1, J4.2, R14.2; also elsewhere on the board
/THERM-3: C11.1, J5.2, R15.2; also elsewhere on the board
/THERM-4: C12.1, J6.2, R16.2; also elsewhere on the board
/THERM-5: C13.1, J7.2, R17.2; also elsewhere on the board
/THERM-6: C14.1, J8.2, R18.2; also elsewhere on the board
/THERM-7: C15.1, J9.2, R19.2; also elsewhere on the board
/THERM-8: C16.1, J10.2, R20.2; also elsewhere on the board
/THERM-10: C18.1, J12.2, R22.2; also elsewhere on the board
/THERM-11: C19.1, J13.2, R23.2; also elsewhere on the board
/THERM-12: C20.1, J14.2, R24.2; also elsewhere on the board
/THERM-13: C21.1, J15.2, R25.2; also elsewhere on the board
/THERM-14: C22.1, J16.2, R26.2; also elsewhere on the board
/THERM-15: C23.1, J17.2, R27.2; also elsewhere on the board
/THERM-16: C24.1, J18.2, R28.2; also elsewhere on the board
GNDA: C9.2, C10.2, C11.2, C12.2, C13.2, C14.2, C15.2, C16.2, C18.2, C19.2, C20.2, C21.2, C22.2, C23.2, C24.2, J3.1, J4.1, J5.1, J6.1, J7.1, J8.1, J9.1, J10.1, J12.1, J13.1, J14.1, J15.1, J16.1, J17.1, J18.1; also elsewhere on the board
VDDA: R13.1, R14.1, R15.1, R16.1, R17.1, R18.1, R19.1, R20.1, R22.1, R23.1, R24.1, R25.1, R26.1, R27.1, R28.1; also elsewhere on the board

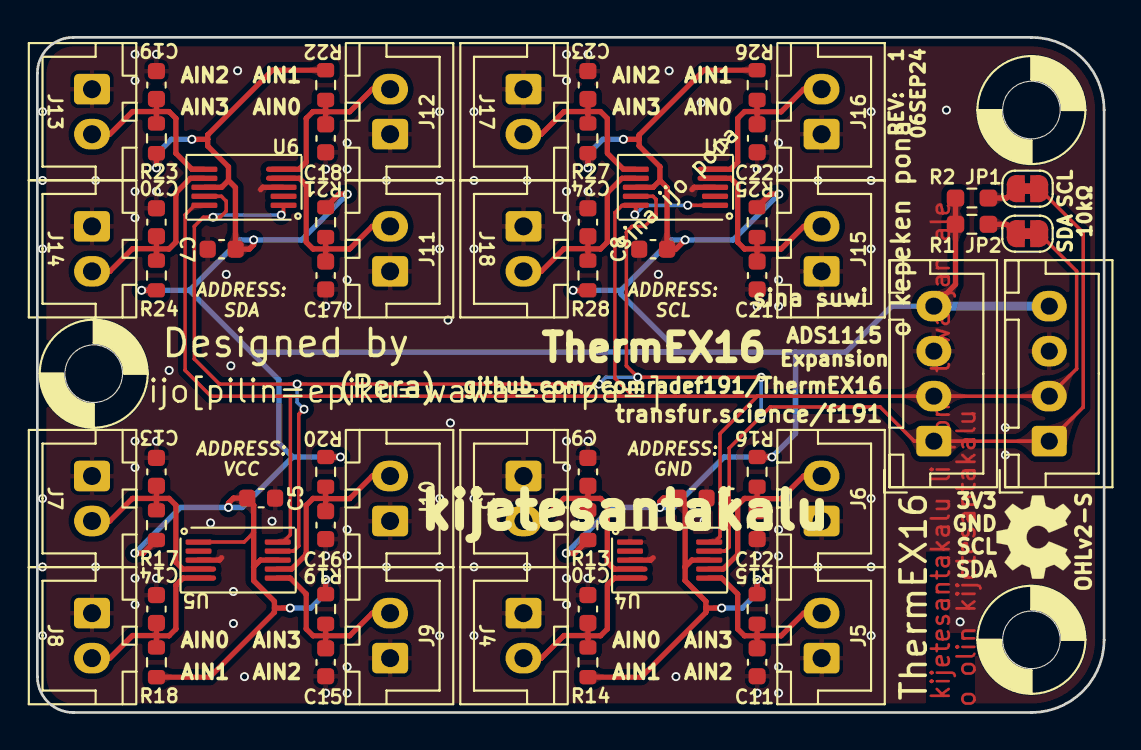
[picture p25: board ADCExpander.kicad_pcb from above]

Board: 2 copper layers, 59.3 x 37.5 mm, 65 parts (0 on the bottom side), 22 nets.

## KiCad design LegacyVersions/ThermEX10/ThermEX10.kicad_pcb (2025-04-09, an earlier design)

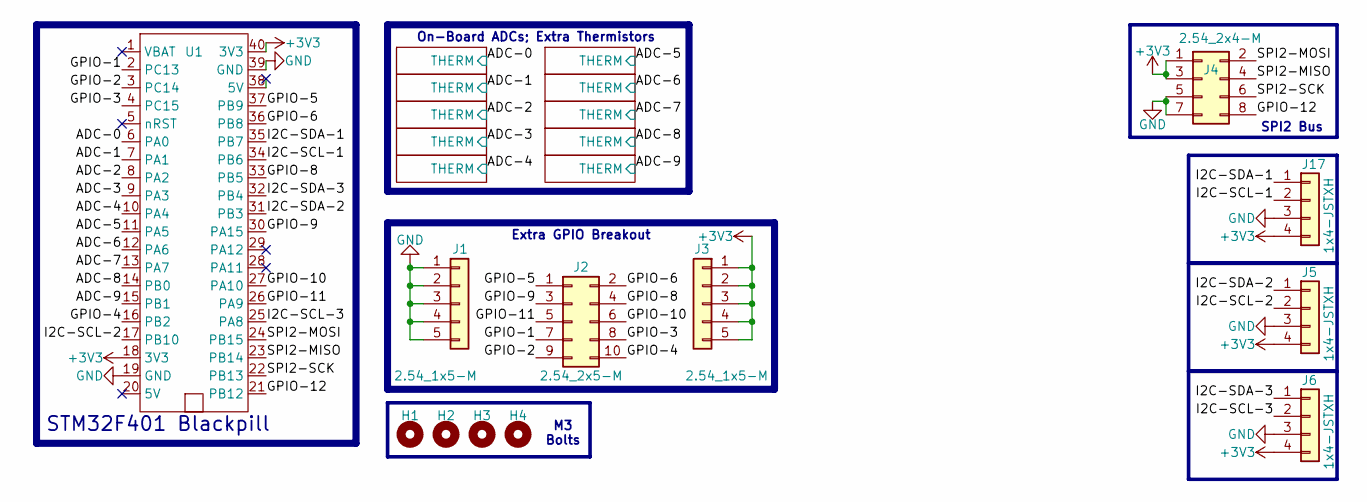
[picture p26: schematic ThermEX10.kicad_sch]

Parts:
H1, H2, H3, H4: M3 Mounting Hole; M3 Mounting Hole ~ Classic
J1, J3: 2.54_1x5-M; PinHeader_1x05_P2.54mm_Vertical
J2: 2.54_2x5-M; PinHeader_2x05_P2.54mm_Vertical
J4: 2.54_2x4-M; PinHeader_2x04_P2.54mm_Vertical
J5, J6, J17: 1x4-JSTXH; JST_XH_B4B-XH-A_1x04_P2.50mm_Vertical; LCSC C144395
U1: Socketed MCU - STM32 BlackPill

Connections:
+3V3: J3.1, J3.2, J3.3, J3.4, J3.5, J4.1, J4.3, J5.4, J6.4, J17.4, U1.18 (3V3), U1.40 (3V3); also elsewhere on the board
/ADC-0: U1.6 (PA0); also elsewhere on the board
/ADC-1: U1.7 (PA1); also elsewhere on the board
/ADC-2: U1.8 (PA2); also elsewhere on the board
/ADC-3: U1.9 (PA3); also elsewhere on the board
/ADC-4: U1.10 (PA4); also elsewhere on the board
/ADC-5: U1.11 (PA5); also elsewhere on the board
/ADC-6: U1.12 (PA6); also elsewhere on the board
/ADC-7: U1.13 (PA7); also elsewhere on the board
/ADC-8: U1.14 (PB0); also elsewhere on the board
/ADC-9: U1.15 (PB1); also elsewhere on the board
/GPIO-1: J2.7, U1.2 (PC13)
/GPIO-2: J2.9, U1.3 (PC14)
/GPIO-3: J2.8, U1.4 (PC15)
/GPIO-4: J2.10, U1.16 (PB2)
/GPIO-5: J2.1, U1.37 (PB9)
/GPIO-6: J2.2, U1.36 (PB8)
/GPIO-8: J2.4, U1.33 (PB5)
/GPIO-9: J2.3, U1.30 (PA15)
/GPIO-10: J2.6, U1.27 (PA10)
/GPIO-11: J2.5, U1.26 (PA9)
/GPIO-12: J4.8, U1.21 (PB12)
/I2C-SCL-1: J17.2, U1.34 (PB6)
/I2C-SCL-2: J5.2, U1.17 (PB10)
/I2C-SCL-3: J6.2, U1.25 (PA8)
/I2C-SDA-1: J17.1, U1.35 (PB7)
/I2C-SDA-2: J5.1, U1.31 (PB3)
/I2C-SDA-3: J6.1, U1.32 (PB4)
/SPI2-MISO: J4.4, U1.23 (PB14)
/SPI2-MOSI: J4.2, U1.24 (PB15)
/SPI2-SCK: J4.6, U1.22 (PB13)
GND: J1.1, J1.2, J1.3, J1.4, J1.5, J4.5, J4.7, J5.3, J6.3, J17.3, U1.19 (GND), U1.39 (GND); also elsewhere on the board

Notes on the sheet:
M3 Bolts
SPI2 Bus
STM32F401 Blackpill
Extra GPIO Breakout
On-Board ADCs; Extra Thermistors

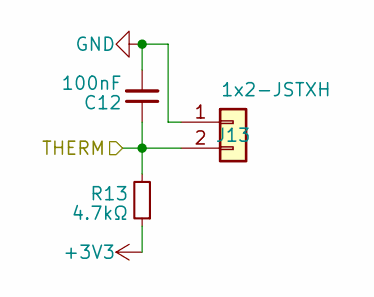
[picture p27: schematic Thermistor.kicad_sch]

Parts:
C12: 100nF; C_0603_1608Metric; LCSC C14663
J13: 1x2-JSTXH; JST-XH_1x02-V ~ Custom; LCSC C5160911
R13: 4.7kΩ; R_0603_1608Metric; LCSC C2989672

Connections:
+3V3: R13.1; also elsewhere on the board
/ADC-6: C12.1, J13.2, R13.2; also elsewhere on the board
GND: C12.2, J13.1; also elsewhere on the board

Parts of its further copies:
C6, C7, C8, C9, C10, C11, C13, C14, C15: 100nF; C_0603_1608Metric; LCSC C14663
J7, J8, J9, J10, J11, J12, J14, J15, J16: 1x2-JSTXH; JST-XH_1x02-V ~ Custom; LCSC C5160911
R7, R8, R9, R10, R11, R12, R14, R15, R16: 4.7kΩ; R_0603_1608Metric; LCSC C2989672

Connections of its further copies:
+3V3: R7.1, R8.1, R9.1, R10.1, R11.1, R12.1, R14.1, R15.1, R16.1; also elsewhere on the board
/ADC-0: C6.1, J7.2, R7.2; also elsewhere on the board
/ADC-1: C7.1, J8.2, R8.2; also elsewhere on the board
/ADC-2: C8.1, J9.2, R9.2; also elsewhere on the board
/ADC-3: C9.1, J10.2, R10.2; also elsewhere on the board
/ADC-4: C10.1, J11.2, R11.2; also elsewhere on the board
/ADC-5: C11.1, J12.2, R12.2; also elsewhere on the board
/ADC-7: C13.1, J14.2, R14.2; also elsewhere on the board
/ADC-8: C14.1, J15.2, R15.2; also elsewhere on the board
/ADC-9: C15.1, J16.2, R16.2; also elsewhere on the board
GND: C6.2, C7.2, C8.2, C9.2, C10.2, C11.2, C13.2, C14.2, C15.2, J7.1, J8.1, J9.1, J10.1, J11.1, J12.1, J14.1, J15.1, J16.1; also elsewhere on the board


Board: 2 copper layers, 79.0 x 39.8 mm, 42 parts (0 on the bottom side), 32 nets.

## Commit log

2025-04-09 Add Legacy Versions
    [ADC-Chip.kicad_sch, ADCExpander.kicad_pcb, ADCExpander.kicad_sch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]
2025-04-09 Add ThermEX26
    [ADS1115.kicad_sch, ThermEX26.kicad_pcb, ThermEX26.kicad_sch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]
2025-04-09 Added titleblocks to drawings
    [ADS1115.kicad_sch, ThermEX26.kicad_sch, Thermistor.kicad_sch]
2025-04-09 Add PDF of schematic & .steps of PCB
    [ThermEX26-Complex.step, ThermEX26-Simple.step]
2025-06-27 im so tired.
    Add warning about what happens when you ignore KiCads warning you're missing a font and export your own files despite said warning.
2025-10-24 Create Project
    [ThermEX-Simple.kicad_pcb, ThermEX-Simple.kicad_sch]
2025-10-24 Simple ThermEX
    [ThermEX-Simple.kicad_pcb, ThermEX-Simple.kicad_sch, ThermEX-Simple.step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]
2025-10-24 Reorganise folders
    [ADS1115.kicad_sch, ThermEX-Simple.kicad_pcb, ThermEX-Simple.kicad_sch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]
2025-10-24 Quick Fix
    [ThermEX-Simple.kicad_pcb, ThermEX-Simple.kicad_sch, Thermistor.kicad_sch]

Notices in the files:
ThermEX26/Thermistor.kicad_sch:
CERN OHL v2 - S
